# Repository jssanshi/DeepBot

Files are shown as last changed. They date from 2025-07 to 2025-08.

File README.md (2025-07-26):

# DeepBot
## 机器人运行 start.py
1. python3.9环境安装依赖:

    ```
    pip install -r requirements.txt
    ```
2. 将service目录拷贝到树莓派目录下
3. 切换到service目录下，启动机器人服务:

    ```
    python start.py
    ```
4.  浏览器访问网页，点击对应按钮操作:

    ```
    http://localhost:8000
    ```
## 远程画面实时监控 start_video.py
1. python3.9环境安装依赖:

    ```
    pip install -r requirements.txt
    ```
2. 将service目录拷贝到树莓派目录下
3. 切换到service目录下，启动机器人服务:

    ```
    python start_video.py
    ```
4.  浏览器访问网页，点击对应按钮操作:

    ```
    http://[localhost/花生壳外网域名]:8000
    ```
## 实时展示摄像机画面 appCamCV2.py 
1.  python3.9运行脚本:

    ```
    python appCamCV2.py
    ```
2.  浏览器访问网页，查看实时画面:

    ```
    http://localhost:8000
    ```
## 实时展示摄像机目标检测画面 appCamCV2_COCO.py 
1. 修改tflite文件路径，coco_labels.txt文件路径:

    ```
    MODEL_PATH = 'model/mobilenet_ssd_v2_coco_quant_postprocess_edgetpu.tflite'
    LABEL_PATH = 'model/coco_labels.txt'
    ```
2. 安装依赖，pycoral安装过程需参考[Coral USB加速器安装调试](https://coral.ai/docs/accelerator/get-started/#3-run-a-model-on-the-edge-tpu).
3. python3.9运行脚本:

    ```
    python appCamCV2_COCO.py
    ```
4. 浏览器访问网页，查看实时目标检测画面:

    ```
    http://localhost:8000
    ```

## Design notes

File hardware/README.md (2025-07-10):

# DeepBot
| 商品名称 | 商品链接 | 型号款式 | 数量 | 商品金额 |
|:---|:---|:---|:---:|:---|
|橡胶车轮 | https://item.taobao.com/item.htm?id=522555599957 | 暂无 | 2 | ￥2.40 |
|机器人马达 | https://item.taobao.com/item.htm?id=522572025351 | 暂无 | 2 | ￥2.90 |
|31合一便携式螺丝刀套装 | https://item.taobao.com/item.htm?id=609467516851 | 暂无 | 1 | ￥10.50 |
|40P彩排杜邦线 | https://item.taobao.com/item.htm?id=558182761958 | 21CM/公对公/40P杜邦线  | 1 | ￥3.61 |
|18650 充电器 | https://item.taobao.com/item.htm?id=537150247135 | 暂无 | 1 | ￥12.50 |
|18650可充电锂电池  | https://item.taobao.com/item.htm?id=522579272027 | 暂无 | 3 | ￥9.90 |
|树莓派4b移动UPS供电模块 | https://item.taobao.com/item.htm?id=619987597182 | UPS HAT | 1 | ￥113.00 |
|40P彩排杜邦线 | https://item.taobao.com/item.htm?id=558182761958 | 21CM/母对公/40P杜邦线  | 1 | ￥3.61 |
|L298N电机 | https://item.taobao.com/item.htm?id=673764907954 | 暂无 | 1 | ￥6.91 |
|18650电池盒带盖带开关 | https://item.taobao.com/item.htm?id=640512917594 | 18650 3节带开关线 串联 | 1 | ￥5.29 |
| 双面胶无痕贴胶带 | https://item.taobao.com/item.htm?id=683691012995 | 25毫米宽*3米长*0.8毫米厚 | 1 | ￥18.80  |
| 304不锈钢十字盘头螺钉 | https://item.taobao.com/item.htm?id=909401645688 | M2*6（50个） | 1 | ￥1.43 |
| 304不锈钢十字盘头螺钉 | https://item.taobao.com/item.htm?id=909401645688 | M2.5*6（50个） | 1 | ￥1.91 |
| 304不锈钢十字盘头螺钉 | https://item.taobao.com/item.htm?id=909401645688 | M3*8（50个） | 1 | ￥2.60 |
| 304不锈钢十字盘头螺钉 | https://item.taobao.com/item.htm?id=909401645688 | M3*6（50个） | 1 | ￥2.32 |
| 304不锈钢十字盘头螺钉 | https://item.taobao.com/item.htm?id=909401645688 | M3*25（20个） | 1 | ￥2.08 |
| 牛眼轮滚珠万向球 | https://item.taobao.com/item.htm?id=632591281487 | CY-12A(全不锈钢） | 2 | ￥4.00 |
| 树莓派4B | https://item.taobao.com/item.htm?id=619656726932 | 基础套餐 4GB | 1 | ￥451.00 |
| Edge TPU USB Accelerator | https://item.taobao.com/item.htm?id=924606720398 | 不含票;G950-06809-01【Coral 原装正品】 | 1 | ￥620.00 |
| 树莓派摄像头 | https://item.taobao.com/item.htm?id=650043465040 | 3.6mm镜头 67度 | 1 | ￥20.80  |

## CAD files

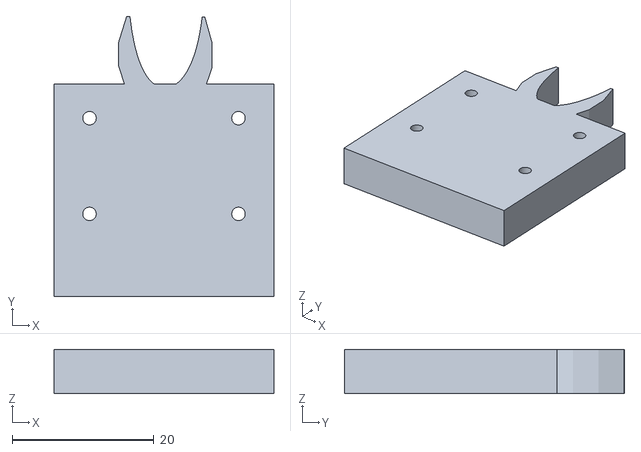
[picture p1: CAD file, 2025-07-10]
hardware/camera - PRINTx1.stl
31.0 x 39.5 x 6.27

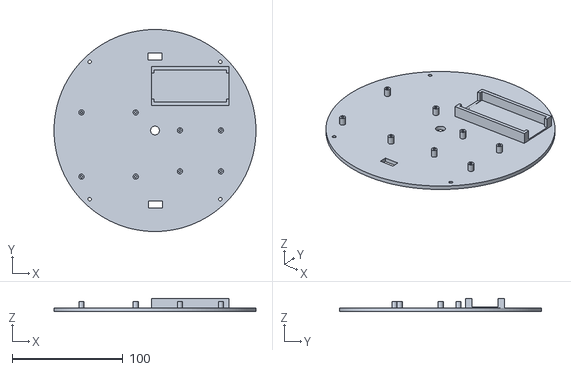
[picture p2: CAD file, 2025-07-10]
hardware/top-chassis - PRINTx1.stl
182.4 x 182.3 x 12.2

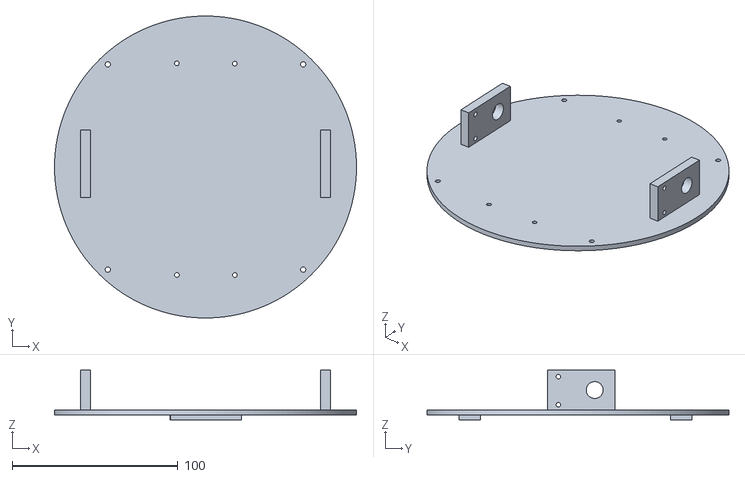
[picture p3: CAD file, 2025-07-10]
hardware/bottom-chassis - PRINTx1.stl
182.4 x 182.3 x 30.0

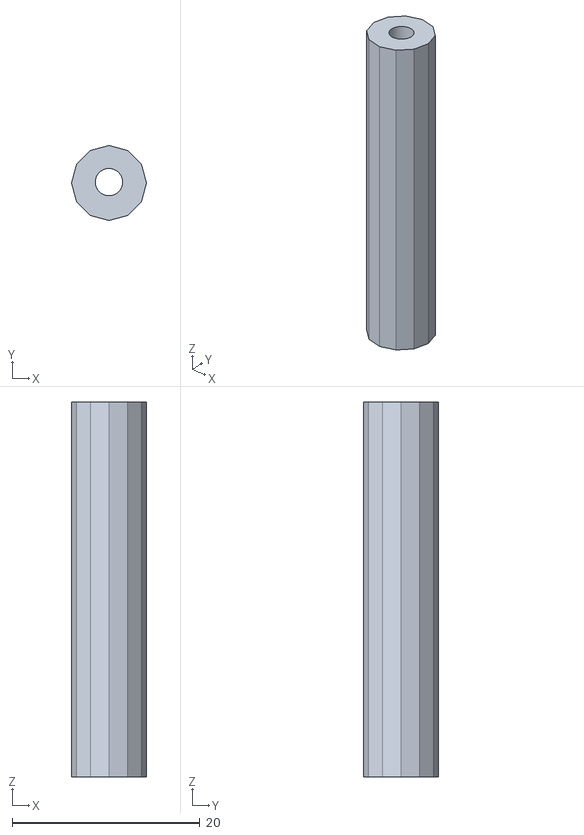
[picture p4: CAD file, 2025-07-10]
hardware/standoffs - PRINTx4.stl
8.00 x 8.00 x 40.0

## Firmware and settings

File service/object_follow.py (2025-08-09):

# 摄像机实时目标检测
import threading
import time
import eventlet
import cv2
from flask import Flask, render_template, Response
from pycoral.adapters import common, detect
from pycoral.utils.edgetpu import make_interpreter
from motor import MotorController

app = Flask(__name__)
mot = MotorController()
SPEED = 20

# 配置
MODEL_PATH = 'model/efficientdet-lite-mario_edgetpu.tflite'
LABEL_PATH = 'model/trained_labels.txt'
FRAME_WIDTH = 640
FRAME_HEIGHT = 480
MAX_WIDTH = 1920
MAX_HEIGHT = 1080
latest_detection_text = "无识别结果"

# 初始化 TPU 模型
interpreter = make_interpreter(MODEL_PATH)
interpreter.allocate_tensors()
interpreter_lock = threading.Lock()

# 加载标签
def load_labels(path):
    labels = {}
    with open(path, 'r') as f:
        for line in f:
            pair = line.strip().split(maxsplit=1)
            if len(pair) == 2:
                labels[int(pair[0])] = pair[1]
    return labels

labels = load_labels(LABEL_PATH)

# 初始化摄像头
camera = cv2.VideoCapture(0)
# 可尝试设置采集格式为 MJPEG（更兼容）
camera.set(cv2.CAP_PROP_FOURCC, cv2.VideoWriter_fourcc(*'MJPG'))
camera.set(cv2.CAP_PROP_FRAME_WIDTH, FRAME_WIDTH)
camera.set(cv2.CAP_PROP_FRAME_HEIGHT, FRAME_HEIGHT)

if not camera.isOpened():
    raise RuntimeError("无法打开摄像头。请检查连接。")

def process_frame(frame):
    if frame is None:
        print("空帧")
        return None

    # 灰度图转BGR三通道
    if len(frame.shape) != 3 or frame.shape[2] != 3:
        print(f"非三通道图像，转换为BGR，shape={frame.shape}")
        frame = cv2.cvtColor(frame, cv2.COLOR_GRAY2BGR)

    # 固定大小，防止尺寸过大导致编码失败
    if frame.shape[1] > MAX_WIDTH or frame.shape[0] > MAX_HEIGHT:
        print(f"图像过大 {frame.shape[1]}x{frame.shape[0]}，缩放中")
        frame = cv2.resize(frame, (FRAME_WIDTH, FRAME_HEIGHT))

    resized = cv2.resize(frame, common.input_size(interpreter))
    rgb_input = cv2.cvtColor(resized, cv2.COLOR_BGR2RGB)
    common.set_input(interpreter, rgb_input)

    with interpreter_lock:
        start = time.time()
        interpreter.invoke()
        inference_time = time.time() - start
        objs = detect.get_objects(interpreter, score_threshold=0.5)

    h, w, _ = frame.shape
    scale_x = w / common.input_size(interpreter)[0]
    scale_y = h / common.input_size(interpreter)[1]

    results = []
    mario_obj = None

    for obj in objs:
        bbox = obj.bbox
        x0, y0 = int(bbox.xmin * scale_x), int(bbox.ymin * scale_y)
        x1, y1 = int(bbox.xmax * scale_x), int(bbox.ymax * scale_y)
        label = labels.get(obj.id, f"ID {obj.id}")
        results.append(f"{label} ({obj.score:.2f})")
        cv2.rectangle(frame, (x0, y0), (x1, y1), (0, 0, 255), 2)
        cv2.putText(frame, f'{label} {obj.score:.2f}', (x0, y0 - 10),
                    cv2.FONT_HERSHEY_SIMPLEX, 0.5, (0, 0, 255), 2)

        # 查找 mario
        if label == "mario":
            mario_obj = (x0, y0, x1, y1)

    # 设置识别结果文本
    global latest_detection_text
    if results:
        latest_detection_text = "，".join(results)
    else:
        latest_detection_text = "未识别到物体"

    cv2.putText(frame, f"Inference: {inference_time*1000:.1f} ms",
                (10, 30), cv2.FONT_HERSHEY_SIMPLEX, 0.6, (0, 255, 255), 2)

    # === 控制逻辑 ===
    if mario_obj:
        x0, y0, x1, y1 = mario_obj
        obj_width = x1 - x0
        #print(f"mario obj_width: {obj_width}")

        obj_center = x0 + obj_width // 2

        # 绘制目标中心点
        cv2.circle(frame, (obj_center, (y0 + y1) // 2), 5, (0, 255, 0), -1)

        offset = obj_center - w // 2
        #print(f"mario 偏移量: {offset}")

        if offset > w // 2.8:
            print("TURN R")
            mot.turn_r(radius=17)
        elif offset < -w // 2.8:
            print("TURN L")
            mot.turn_l(radius=14)
        elif obj_width < w // 2.8:
            print("FORWARD")
            mot.forward(dc=SPEED)
        else:
            print("STOP - mario 太近")
            mot.stop()
    else:
        mot.stop()

    return frame

def gen_frames():
    while True:
        success, frame = camera.read()
        if not success or frame is None:
            print("读取摄像头帧失败")
            continue

        # 只有3维（H,W,3）才旋转，否则跳过
        if len(frame.shape) == 3 and frame.shape[2] == 3:
            frame = cv2.rotate(frame, cv2.ROTATE_180)
        else:
            print(f"跳过旋转，frame shape异常: {frame.shape}")

        # 如果是灰度图，转换成BGR三通道
        if len(frame.shape) == 2:
            frame = cv2.cvtColor(frame, cv2.COLOR_GRAY2BGR)

        # 防止尺寸过大
        if frame.shape[1] > MAX_WIDTH or frame.shape[0] > MAX_HEIGHT:
            print(f"图像过大 {frame.shape[1]}x{frame.shape[0]}，缩放中")
            frame = cv2.resize(frame, (FRAME_WIDTH, FRAME_HEIGHT))

        processed = process_frame(frame)
        if processed is None:
            continue

        ret, buffer = cv2.imencode('.jpg', processed)
        if not ret:
            print("编码帧失败")
            continue

        frame_bytes = buffer.tobytes()
        yield (b'--frame\r\n'
               b'Content-Type: image/jpeg\r\n\r\n' + frame_bytes + b'\r\n')

        eventlet.sleep(0.01)

def get_latest_detection_result():
    global latest_detection_text
    return latest_detection_text

@app.route('/')
def index():
    return render_template('camera_tpu.html')

@app.route('/video_feed')
def video_feed():
    return Response(gen_frames(),
                    mimetype='multipart/x-mixed-replace; boundary=frame')
@app.route('/model_output')
def model_output():
    return get_latest_detection_result()

if __name__ == '__main__':
    app.run(host='0.0.0.0', port=8000, debug=False, threaded=True)

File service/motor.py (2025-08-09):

"""GPIO Controller for L298"""
import RPi.GPIO as GPIO
import time


# Left (BCM)
LEFT_IN3 = 27
LEFT_IN4 = 22
LEFT_ENB = 17

# Right (BCM)
RIGHT_ENA = 18
RIGHT_IN1 = 14
RIGHT_IN2 = 15

PINS = {"L": {"EN": LEFT_ENB, "IN1": LEFT_IN3, "IN2": LEFT_IN4},
        "R": {"EN": RIGHT_ENA, "IN1": RIGHT_IN1, "IN2": RIGHT_IN2}}

BALANCE_SPEED = 3
INIT_SPEED = 6

class MotorController(object):
    """GPIO Controller for L298."""

    def __init__(self):
        super(MotorController, self).__init__()

        GPIO.setmode(GPIO.BCM)
        for k in PINS.keys():
            GPIO.setup(PINS[k]["EN"],  GPIO.OUT)
            GPIO.setup(PINS[k]["IN1"], GPIO.OUT)
            GPIO.setup(PINS[k]["IN2"], GPIO.OUT)
        self.pwm = {"L": GPIO.PWM(PINS["L"]["EN"], 20),
                    "R": GPIO.PWM(PINS["R"]["EN"], 20)}

    def __del__(self):
        self.stop()
        self.cleanup()

    def stop(self):
        for k in PINS.keys():
            GPIO.output(PINS[k]["EN"],  GPIO.LOW)
            GPIO.output(PINS[k]["IN1"], GPIO.LOW)
            GPIO.output(PINS[k]["IN2"], GPIO.LOW)
        print("=====stop=====")

    def forcebreak(self):
        for k in PINS.keys():
            GPIO.output(PINS[k]["EN"],  GPIO.HIGH)
            GPIO.output(PINS[k]["IN1"], GPIO.LOW)
            GPIO.output(PINS[k]["IN2"], GPIO.LOW)

    def _forward(self, k, dc=INIT_SPEED):
        GPIO.output(PINS[k]["IN1"], GPIO.HIGH)
        GPIO.output(PINS[k]["IN2"], GPIO.LOW)
        self.pwm[k].start(dc)

    def _reverse(self, k, dc=INIT_SPEED):
        GPIO.output(PINS[k]["IN1"], GPIO.LOW)
        GPIO.output(PINS[k]["IN2"], GPIO.HIGH)
        self.pwm[k].start(dc)

    def forward(self, duration=None, dc=INIT_SPEED):
        self._forward("L", dc + BALANCE_SPEED)
        self._forward("R", dc)
        if duration:
            time.sleep(duration)

    def reverse(self, duration=None, dc=INIT_SPEED):
        self._reverse("L", dc + BALANCE_SPEED)
        self._reverse("R", dc)
        if duration:
            time.sleep(duration)

    def rotate(self, duration=None, dc=INIT_SPEED):
        self._reverse("L", dc/1.5 + BALANCE_SPEED)
        self._forward("R", dc/1.5)
        if duration:
            time.sleep(duration)

    def turn_l(self, radius=0, duration=None):
        if radius > 0:
            self._forward("R", radius)
            self._forward("L", 0)
        else:
            self._reverse("L")
            self._forward("R")
        if duration:
            time.sleep(duration)

    def turn_r(self, radius=0, duration=None):
        if radius > 0:
            self._forward("R", 0)
            self._forward("L", radius)
        else:
            self._forward("L")
            self._reverse("R")
        if duration:
            time.sleep(duration)

    def cleanup(self):
        GPIO.cleanup()
        print("=====cleanup=====")

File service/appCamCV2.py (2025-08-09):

# 摄像机实时画面
from flask import Flask, render_template, Response
import cv2
 
app = Flask(__name__)

@app.route('/')
def index():
    """Video streaming home page."""
    return render_template('camera.html')

def gen_frames():
    camera = cv2.VideoCapture(0)
    # 可尝试设置采集格式为 MJPEG（更兼容）
    camera.set(cv2.CAP_PROP_FOURCC, cv2.VideoWriter_fourcc(*'MJPG'))
    camera.set(cv2.CAP_PROP_FRAME_WIDTH, 640)
    camera.set(cv2.CAP_PROP_FRAME_HEIGHT, 480)

    while True:
        success, frame = camera.read()
        #frame = cv2.rotate(frame, cv2.ROTATE_180)
        if not success:
            print("Failed to read frame")
            continue

        try:
            # 确保图像是 BGR 格式，不是灰度或压缩格式
            if len(frame.shape) == 2 or frame.shape[2] == 1:
                # 单通道图像 → 转 BGR（虽然不常见）
                frame = cv2.cvtColor(frame, cv2.COLOR_GRAY2BGR)
            elif frame.shape[2] == 2:
                # 可能是 YUYV → 转换
                frame = cv2.cvtColor(frame, cv2.COLOR_YUV2BGR_YUY2)

            # 缩小分辨率避免编码异常
            frame = cv2.resize(frame, (640, 480), interpolation=cv2.INTER_AREA)

            # 编码为 JPEG
            ret, buffer = cv2.imencode('.jpg', frame)
            if not ret:
                continue

            yield (b'--frame\r\n'
                   b'Content-Type: image/jpeg\r\n\r\n' + buffer.tobytes() + b'\r\n')

        except Exception as e:
            print(f"[ERROR] Encoding failed: {e}")

@app.route('/video_feed')
def video_feed():
    """Video streaming route. Put this in the src attribute of an img tag."""
    return Response(gen_frames(),
                    mimetype='multipart/x-mixed-replace; boundary=frame')
 
if __name__ == '__main__':
    app.run(host='0.0.0.0', port =8000, debug=True, threaded=True)

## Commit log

2025-06-07 使用 Colab 创建而成
2025-06-29 (feat): tpu with camera
2025-07-10 (feat): 3D printer, bot control
    [bottom-chassis - PRINTx1.stl, camera - PRINTx1.stl, standoffs - PRINTx4.stl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]
2025-07-31 (feat): 拍照采集图片
2025-07-31 (feat): 训练马里奥mario识别模型
2025-08-09 (feat): 识别马里奥，自动导航
